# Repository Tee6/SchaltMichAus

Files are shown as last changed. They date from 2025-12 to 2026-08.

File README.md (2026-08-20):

# SchaltMichAus

**SchaltMichAus** is a smart add-on for my audio setup (Yamaha RX-V1065), now built around **Home Assistant** as the primary control layer via **MQTT**.
It monitors the receiver's activity, exposes trigger/music state as Home Assistant entities, and automatically shuts down the receiver via IR when no audio is playing.

**Goal:**
Reduce energy consumption, avoid unnecessary idle time, and extend the lifetime of the receiver – fully integrated into my smart home, without changing how the setup is normally used.

## Motivation

I inherited a Yamaha RX-V1065 from my grandpa.
Whenever someone in the flat listened to music in the evening, we often forgot to turn the amplifier off. Managing the peripherals manually or switching the TV audio output every time was inconvenient. I wanted a solution that:

- does not change how the receiver is used,
- requires no firmware or hardware modifications to the receiver itself,
- integrates cleanly into Home Assistant,
- and keeps the device as my grandpa left it.

## Features

- **Home Assistant integration (MQTT)**
  - ESP32 publishes trigger state, music-active state, and switch state via MQTT with HA Discovery – all entities show up automatically in Home Assistant, no manual YAML config needed.
  - A dedicated switch entity lets me manually trigger a shutdown from HA, alongside automations (e.g. tied to presence, time of day, or other smart home logic).
  - This is now the main way the system is operated day-to-day.

- **Automatic idle detection**
  - Monitors the receiver's 12 V trigger output.
  - Analyzes the audio-out signal to detect real audio activity.
  - Marks the system as "inactive" after a configurable silence timeout.

- **Input Switching and Volume Control**
  - Can switch between Inputs for Record Player (Phono) and TV (Audio1).
  - With Home Assistant Automations, the Input gets automatically set for the TV and in the Future maybe even for the record player with an DIY sensor when i open the record player.
  - Volume can be controlled with Home Assistant.
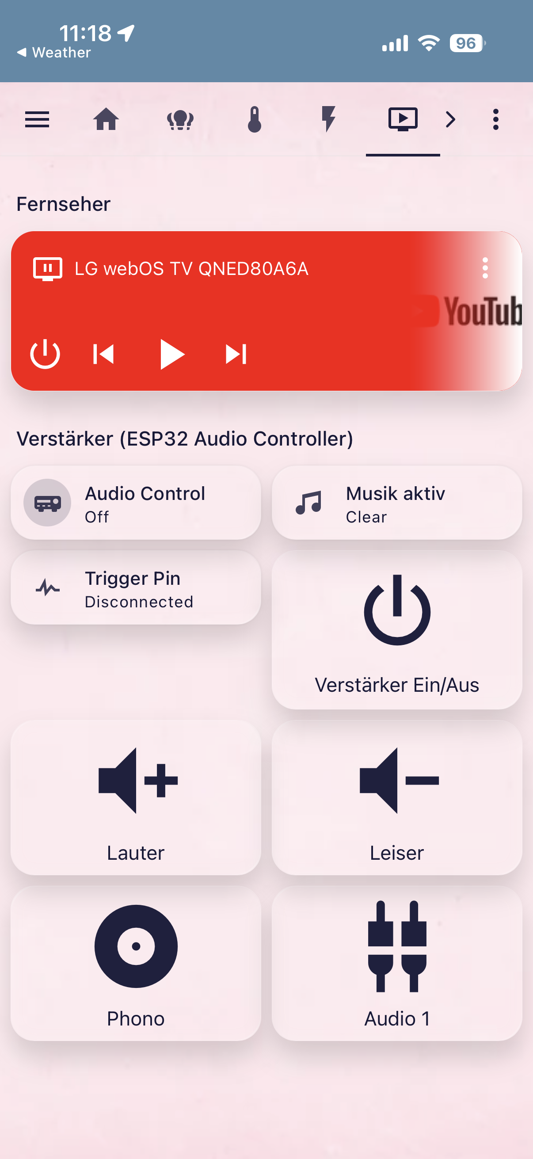
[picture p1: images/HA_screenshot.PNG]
Home Assistant Dashboard


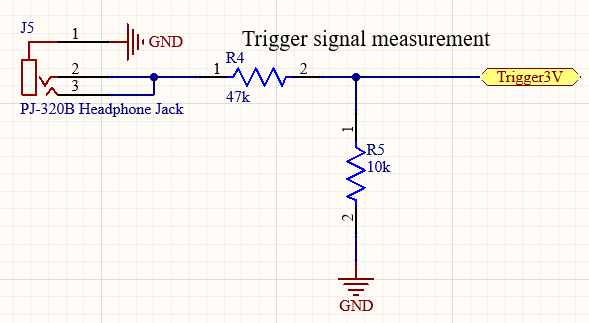
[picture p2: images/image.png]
Trigger Voltage measurement


Simple Voltage Divider

$U_m=12V*{10k\Omega \above{2pt} 10k\Omega+47k\Omega} \approx 2.1V$

- **Automatic receiver power-down – hardware fallback**
  - Independently of Home Assistant, the ESP32 itself tracks a **20-minute silence timeout**: if no music activity is detected for 20 minutes, it sends IR commands to the receiver for a clean shutdown – just like a remote.
  - This runs locally on the ESP32 regardless of whether HA, MQTT, or WiFi are available, so the amp still gets shut off even if the smart home stack is down.

- **Load switch (present on PCB, currently unused)**
  - The custom PCB still includes a load switch, originally used to power down the ARC extractor and other peripherals.
  - Since the ARC extractor is no longer part of the setup (audio now goes via Bluetooth), the load switch is not currently used in this use case, but remains available on the board for future peripherals if needed.

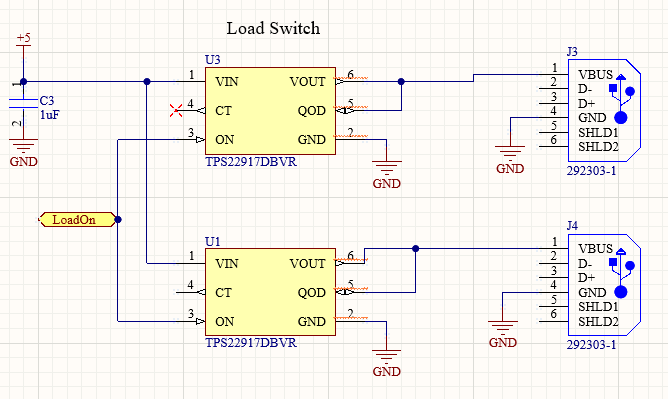
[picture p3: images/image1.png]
LoadSwitches


Load Switches parallel so the current is less of a problem. We only need Power so D- and D+ are left floating.

- **Non-intrusive integration**
  - Installed between the receiver's audio/trigger outputs and the peripherals.
  - Requires no modification of the receiver.
  - Works completely in the background.

- **Smart audio detection**
  - Uses a DC-biased input and statistical deviation ("loudness over time") to detect meaningful audio.
  - Avoids false shutdowns during quiet passages or short pauses.

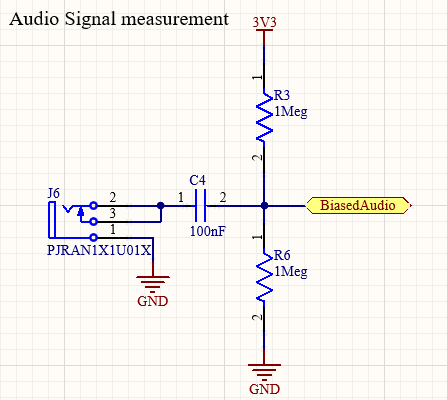
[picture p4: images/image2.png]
audio-measurement


Audio Signal is biased to $3.3V / 2 =1.65V$ because IO Pin cant handle negative Voltage

- **Bluetooth audio path (replaces ARC extractor)**
  - The previous ARC extractor is no longer used.
  - The TV now sends its audio directly to the receiver over **Bluetooth**, simplifying the signal chain and removing the extra ARC hardware step entirely.

## Typical Use Case

1. TV audio is streamed to the receiver via Bluetooth (or another source is played, e.g. turntable via phono).
2. SchaltMichAus detects the active state via the trigger signal and begins monitoring audio.
3. Trigger and music state are visible live in Home Assistant, and I can control shutdown manually or via HA automations.
4. During playback, the receiver stays on; ESP32 and Bluetooth module run continuously in the background regardless.
5. After playback stops:
   - If controlled via Home Assistant, automations can react to the published state as configured.
   - Independently, after the configured silence interval (20 min) passes with no music detected, the receiver is turned off via IR – this happens regardless of HA availability.

**Result:**
No more receiver running for hours after someone forgot to turn it off, now with full Home Assistant visibility and control on top of the standalone hardware safety net.

## Hardware Overview

- **Controller:** ESP32 (AZ-Delivery version)
- **Inputs:**
  - 5 V via USB-C
  - 12 V trigger input
  - Audio-out signal (approx. ±1 V)
- **Outputs:**
  - IR LED for power commands to the receiver
  - Load switch (on PCB, currently unused – previously powered ARC extractor)
- **Connectivity:**
  - MQTT to Home Assistant, with HA Discovery for switch, trigger, and music-active entities
  - Bluetooth receiver module (TV → receiver audio path), running continuously

## Status

- Home Assistant / MQTT integration: **working**
- IR on/off control: **working**
- Trigger signal monitoring: **working**
- Audio-based idle detection: **working**
- 20-minute hardware silence shutdown (independent of HA): **working**
- Bluetooth audio path (TV → receiver): **working**
- Custom PCB with ESP32, audio and trigger inputs, load switch: **working** (load switch currently unused in this setup)

## Initial Problems

- The first ESP32 unit was unreliable, causing inconsistent behaviour → resolved by replacing it.
- Audio detection pin was not ADC-capable → fixed by soldering a jumper wire to a valid ADC pin.

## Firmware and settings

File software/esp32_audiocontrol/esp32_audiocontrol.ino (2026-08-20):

#include <Arduino.h>
#define MQTT_MAX_PACKET_SIZE 1024

#include <WiFi.h>
#include <IRremoteESP8266.h>
#include <IRsend.h>
#include <string.h>
#include <PubSubClient.h>

// ---------------- WLAN ----------------
const char* ssid = "";
const char* password = "";

// ---------------- MQTT ----------------
const char* mqttBroker   = "192.168.178.113"; // ggf. ändern
const int   mqttPort     = 1883;
const char* mqttUser     = "esp32";
const char* mqttPassword = "esp32";

#define MQTT_PREFIX        "homeassistant"
#define DEVICE_ID          "esp32_audiocontrol"

#define TOPIC_SWITCH_CMD    DEVICE_ID "/switch/control/set"
#define TOPIC_SWITCH_STATE  DEVICE_ID "/switch/control/state"
#define TOPIC_TRIGGER_STATE DEVICE_ID "/binary_sensor/trigger/state"
#define TOPIC_MUSIC_STATE   DEVICE_ID "/binary_sensor/music/state"
#define TOPIC_IR_CMD        DEVICE_ID "/button/ir_send/set"
#define TOPIC_IR_EVENT      DEVICE_ID "/sensor/ir_event/state"

#define TOPIC_DISC_SWITCH   MQTT_PREFIX "/switch/"        DEVICE_ID "_control/config"
#define TOPIC_DISC_TRIGGER  MQTT_PREFIX "/binary_sensor/" DEVICE_ID "_trigger/config"
#define TOPIC_DISC_MUSIC    MQTT_PREFIX "/binary_sensor/" DEVICE_ID "_music/config"
#define TOPIC_DISC_IR       MQTT_PREFIX "/button/"        DEVICE_ID "_ir_send/config"
#define TOPIC_DISC_IR_EVENT MQTT_PREFIX "/sensor/"        DEVICE_ID "_ir_event/config"

// NEU: Discovery-Topics für die vier zusätzlichen Buttons
#define TOPIC_DISC_VOL_UP   MQTT_PREFIX "/button/" DEVICE_ID "_vol_up/config"
#define TOPIC_DISC_VOL_DOWN MQTT_PREFIX "/button/" DEVICE_ID "_vol_down/config"
#define TOPIC_DISC_PHONO    MQTT_PREFIX "/button/" DEVICE_ID "_in_phono/config"
#define TOPIC_DISC_AUDIO1   MQTT_PREFIX "/button/" DEVICE_ID "_in_audio1/config"

// ---------------- Pins ----------------
#define PIN_TRIGGER 32
#define PIN_IR      18
#define AUX_PIN     34

// ---------------- Audio ----------------
#define SAMPLE_COUNT      1000
const float THRESH_ON   =  8.0f;
const float THRESH_OFF  = 12.0f;
#define MUSIC_ON_CONFIRM  3
#define MUSIC_OFF_CONFIRM 6

float g_silenceMinutes = 20.0f;

// Mindest-Wartezeit nach Trigger-HIGH bevor Silence-Timeout greifen darf
const unsigned long TRIGGER_GRACE_MS = 30000UL;  // 30 Sekunden

// Schutzfenster nach MQTT-Connect: retained Messages in diesem Fenster ignorieren
const unsigned long MQTT_RETAINED_IGNORE_MS = 2000UL;

// Debounce für manuellen POWER-Press: verhindert Doppel-Toggle egal welche Ursache
const unsigned long MANUAL_IR_DEBOUNCE_MS = 3000UL;

// Kurzer Debounce für Vol/Input: nur gegen MQTT-Doppelzustellung,
// darf schnelles wiederholtes Drücken (Lautstärke!) NICHT blockieren
const unsigned long SHORT_IR_DEBOUNCE_MS = 250UL;

// ---------------- Timing ----------------
const unsigned long MUSIC_CHECK_MS        = 3000UL;
const unsigned long STATE_PRINT_MS        = 5000UL;
const unsigned long IR_INTERVAL_MS        = 2000UL;
const unsigned long MQTT_RECONNECT_MS     = 10000UL;
const unsigned long WIFI_RECONNECT_MS     = 15000UL;
const unsigned long DISCOVERY_INTERVAL_MS = 300000UL;

// ---------------- Yamaha IR Codes (aus LIRC RAV294 / RX-V1065) ----------------
#define YAMAHA_KEY_POWER   0x7E8154AB
#define YAMAHA_VOL_UP      0x5EA158A7   // KEY_VOLUMEUP
#define YAMAHA_VOL_DOWN    0x5EA1D827   // KEY_VOLUMEDOWN
#define YAMAHA_IN_PHONO    0x5EA128D7   // INPUT_PHONO
#define YAMAHA_IN_AUDIO1   0x5EA1A658   // INPUT_AUDIO1

// ---------------- Globals ----------------
WiFiClient   wifiClient;
PubSubClient mqtt(wifiClient);
IRsend       irsend(PIN_IR);

bool g_wifiReady       = false;
bool g_haControlOn     = false;
bool g_haControlOff    = false;

bool g_lastTriggerPub  = false;
bool g_lastMusicPub    = false;
bool g_musicActive     = false;
bool g_shutdownMode    = false;
bool g_triggerState    = false;
bool g_musicEverActive = false;

int  g_musicOnCounter  = 0;
int  g_musicOffCounter = 0;

unsigned long g_lastIrSendTime    = 0;
unsigned long g_lastMqttAttempt   = 0;
unsigned long g_lastWifiAttempt   = 0;
unsigned long g_lastMusicTime     = 0;
unsigned long g_triggerHighTime   = 0;
unsigned long g_mqttConnectedAt   = 0;
unsigned long g_lastManualIrTime  = 0;
unsigned long g_lastShortIrTime   = 0;

// ================================================================
// Forward Declarations
// ================================================================
void sendIR(const char* reason);
void sendIRCode(uint32_t code, const char* reason);
void publishSwitchState(bool on);
void publishTriggerState(bool on);
void publishMusicState(bool on);
void publishIrEvent(const char* reason);
void publishDiscovery();
void ensureMQTT();
void ensureWiFi();

// ================================================================
// WiFi – non-blocking
// ================================================================
void ensureWiFi() {
  if (WiFi.status() == WL_CONNECTED) { g_wifiReady = true; return; }
  wl_status_t s = WiFi.status();
  if (s == WL_DISCONNECTED || s == WL_NO_SSID_AVAIL || s == WL_CONNECT_FAILED) {
    WiFi.mode(WIFI_STA);
    WiFi.begin(ssid, password);
  }
  g_wifiReady = (WiFi.status() == WL_CONNECTED);
}

// ================================================================
// MQTT Discovery
// ================================================================
void publishDiscovery() {
  mqtt.publish(TOPIC_DISC_SWITCH,
    "{"
      "\"name\":\"Audio Control\","
      "\"unique_id\":\"" DEVICE_ID "_control\","
      "\"command_topic\":\"" TOPIC_SWITCH_CMD "\","
      "\"state_topic\":\"" TOPIC_SWITCH_STATE "\","
      "\"payload_on\":\"ON\","
      "\"payload_off\":\"OFF\","
      "\"retain\":true,"
      "\"device\":{"
        "\"identifiers\":[\"" DEVICE_ID "\"],"
        "\"name\":\"ESP32 Audio Controller\","
        "\"model\":\"ESP32\","
        "\"manufacturer\":\"DIY\""
      "}"
    "}", true);

  mqtt.publish(TOPIC_DISC_TRIGGER,
    "{"
      "\"name\":\"Trigger Pin\","
      "\"unique_id\":\"" DEVICE_ID "_trigger\","
      "\"state_topic\":\"" TOPIC_TRIGGER_STATE "\","
      "\"payload_on\":\"ON\","
      "\"payload_off\":\"OFF\","
      "\"device_class\":\"connectivity\","
      "\"retain\":true,"
      "\"device\":{\"identifiers\":[\"" DEVICE_ID "\"],\"name\":\"ESP32 Audio Controller\"}"
    "}", true);

  mqtt.publish(TOPIC_DISC_MUSIC,
    "{"
      "\"name\":\"Musik aktiv\","
      "\"unique_id\":\"" DEVICE_ID "_music\","
      "\"state_topic\":\"" TOPIC_MUSIC_STATE "\","
      "\"payload_on\":\"ON\","
      "\"payload_off\":\"OFF\","
      "\"device_class\":\"sound\","
      "\"retain\":true,"
      "\"device\":{\"identifiers\":[\"" DEVICE_ID "\"],\"name\":\"ESP32 Audio Controller\"}"
    "}", true);

  mqtt.publish(TOPIC_DISC_IR,
    "{"
      "\"name\":\"IR Senden\","
      "\"unique_id\":\"" DEVICE_ID "_ir_send\","
      "\"command_topic\":\"" TOPIC_IR_CMD "\","
      "\"payload_press\":\"PRESS\","
      "\"device\":{"
        "\"identifiers\":[\"" DEVICE_ID "\"],"
        "\"name\":\"ESP32 Audio Controller\","
        "\"model\":\"ESP32\","
        "\"manufacturer\":\"DIY\""
      "}"
    "}", true);

  // NEU: Vier weitere Buttons. Gleiches command_topic, unterschiedliche payload_press.
  // Vorteil: nur eine Subscription, Retained-Handling & Startup-Schutz gelten automatisch.
  mqtt.publish(TOPIC_DISC_VOL_UP,
    "{"
      "\"name\":\"Lautstärke +\","
      "\"unique_id\":\"" DEVICE_ID "_vol_up\","
      "\"command_topic\":\"" TOPIC_IR_CMD "\","
      "\"payload_press\":\"VOL_UP\","
      "\"icon\":\"mdi:volume-plus\","
      "\"device\":{\"identifiers\":[\"" DEVICE_ID "\"],\"name\":\"ESP32 Audio Controller\"}"
    "}", true);

  mqtt.publish(TOPIC_DISC_VOL_DOWN,
    "{"
      "\"name\":\"Lautstärke -\","
      "\"unique_id\":\"" DEVICE_ID "_vol_down\","
      "\"command_topic\":\"" TOPIC_IR_CMD "\","
      "\"payload_press\":\"VOL_DOWN\","
      "\"icon\":\"mdi:volume-minus\","
      "\"device\":{\"identifiers\":[\"" DEVICE_ID "\"],\"name\":\"ESP32 Audio Controller\"}"
    "}", true);

  mqtt.publish(TOPIC_DISC_PHONO,
    "{"
      "\"name\":\"Input Phono\","
      "\"unique_id\":\"" DEVICE_ID "_in_phono\","
      "\"command_topic\":\"" TOPIC_IR_CMD "\","
      "\"payload_press\":\"PHONO\","
      "\"icon\":\"mdi:album\","
      "\"device\":{\"identifiers\":[\"" DEVICE_ID "\"],\"name\":\"ESP32 Audio Controller\"}"
    "}", true);

  mqtt.publish(TOPIC_DISC_AUDIO1,
    "{"
      "\"name\":\"Input Audio1\","
      "\"unique_id\":\"" DEVICE_ID "_in_audio1\","
      "\"command_topic\":\"" TOPIC_IR_CMD "\","
      "\"payload_press\":\"AUDIO1\","
      "\"icon\":\"mdi:audio-input-rca\","
      "\"device\":{\"identifiers\":[\"" DEVICE_ID "\"],\"name\":\"ESP32 Audio Controller\"}"
    "}", true);

  mqtt.publish(TOPIC_DISC_IR_EVENT,
    "{"
      "\"name\":\"IR Letzter Grund\","
      "\"unique_id\":\"" DEVICE_ID "_ir_event\","
      "\"state_topic\":\"" TOPIC_IR_EVENT "\","
      "\"retain\":true,"
      "\"icon\":\"mdi:remote\","
      "\"device\":{"
        "\"identifiers\":[\"" DEVICE_ID "\"],"
        "\"name\":\"ESP32 Audio Controller\","
        "\"model\":\"ESP32\","
        "\"manufacturer\":\"DIY\""
      "}"
    "}", true);
}

// ================================================================
// MQTT Callback
// ================================================================
void mqttCallback(char* topic, byte* payload, unsigned int length) {
  char msg[16] = {0};
  unsigned int copyLen = (length < 15) ? length : 15;
  memcpy(msg, payload, copyLen);
  Serial.printf("MQTT [%s]: %s\n", topic, msg);

  if (strcmp(topic, TOPIC_SWITCH_CMD) == 0) {
    if (strcmp(msg, "ON") == 0) {
      g_haControlOn  = true;
      g_haControlOff = false;
    } else if (strcmp(msg, "OFF") == 0) {
      if (millis() - g_mqttConnectedAt < MQTT_RETAINED_IGNORE_MS) {
        Serial.println("MQTT OFF ignoriert: retained (Startup)");
        publishSwitchState(true);
      } else {
        g_haControlOff = true;
        g_haControlOn  = false;
      }
    }
  }

  if (strcmp(topic, TOPIC_IR_CMD) == 0) {

    // FIX: nur clearen wenn die Nachricht tatsächlich Inhalt hatte.
    // Vorher wurde hier IMMER (auch bei leerer Nachricht) erneut auf
    // dasselbe Topic publiziert, auf das der ESP32 selbst subscribed ist.
    // Das erzeugte eine Self-Feedback-Loop: publish("") -> eigener Empfang
    // -> erneutes publish("") -> ... im Millisekundentakt.
    if (length > 0) {
      mqtt.publish(TOPIC_IR_CMD, "", true);  // Retained Press löschen
    } else {
      return;  // leere Clear-Nachricht: nichts weiter tun
    }

    unsigned long now = millis();

    // Schutzfenster: Press kurz nach Connect = retained, ignorieren.
    // Gilt für ALLE Button-Payloads (POWER, VOL, INPUT).
    if (millis() - g_mqttConnectedAt < MQTT_RETAINED_IGNORE_MS) {
      Serial.println("MQTT Press ignoriert: retained (Startup)");
      return;
    }

    // ---- POWER (langer Debounce, Doppel-Toggle wäre fatal) ----
    if (strcmp(msg, "PRESS") == 0) {
      if (now - g_lastManualIrTime < MANUAL_IR_DEBOUNCE_MS) {
        Serial.println("MQTT IR PRESS ignoriert: Debounce (zu kurz nach letztem Press)");
        return;
      }
      g_lastManualIrTime = now;
      Serial.println("HA Button: IR manuell (POWER)");
      sendIR("manual_ha");
      return;
    }

    // ---- Vol/Input (kurzer Debounce: schnelles Drücken erlaubt) ----
    if (now - g_lastShortIrTime < SHORT_IR_DEBOUNCE_MS) {
      Serial.println("MQTT Press ignoriert: Kurz-Debounce");
      return;
    }

    if (strcmp(msg, "VOL_UP") == 0) {
      g_lastShortIrTime = now;
      sendIRCode(YAMAHA_VOL_UP, "vol_up");
    } else if (strcmp(msg, "VOL_DOWN") == 0) {
      g_lastShortIrTime = now;
      sendIRCode(YAMAHA_VOL_DOWN, "vol_down");
    } else if (strcmp(msg, "PHONO") == 0) {
      g_lastShortIrTime = now;
      sendIRCode(YAMAHA_IN_PHONO, "input_phono");
    } else if (strcmp(msg, "AUDIO1") == 0) {
      g_lastShortIrTime = now;
      sendIRCode(YAMAHA_IN_AUDIO1, "input_audio1");
    }
  }
}

// ================================================================
// MQTT Reconnect
// ================================================================
void ensureMQTT() {
  if (mqtt.connected() || !g_wifiReady) return;
  Serial.print("MQTT verbinden...");
  mqtt.setKeepAlive(60);
  bool ok = (strlen(mqttUser) > 0)
    ? mqtt.connect(DEVICE_ID, mqttUser, mqttPassword)
    : mqtt.connect(DEVICE_ID);
  if (ok) {
    Serial.println(" OK");
    g_mqttConnectedAt = millis();  // bei JEDEM Connect (auch Reconnect) setzen
    mqtt.subscribe(TOPIC_SWITCH_CMD);
    mqtt.subscribe(TOPIC_IR_CMD);
    delay(500);
    publishDiscovery();
  } else {
    Serial.printf(" fehlgeschlagen rc=%d\n", mqtt.state());
  }
}

// ================================================================
// Publish Helpers
// ================================================================
void publishSwitchState(bool on) {
  if (mqtt.connected()) mqtt.publish(TOPIC_SWITCH_STATE, on ? "ON" : "OFF", true);
}
void publishTriggerState(bool on) {
  if (mqtt.connected()) mqtt.publish(TOPIC_TRIGGER_STATE, on ? "ON" : "OFF", true);
}
void publishMusicState(bool on) {
  if (mqtt.connected()) mqtt.publish(TOPIC_MUSIC_STATE, on ? "ON" : "OFF", true);
}

void publishIrEvent(const char* reason) {
  if (!mqtt.connected()) return;
  char payload[128];
  snprintf(payload, sizeof(payload),
    "{\"reason\":\"%s\",\"ts\":%lu}", reason, millis());
  mqtt.publish(TOPIC_IR_EVENT, payload, true);
}

// ================================================================
// IR – generisch mit Code + Grund
// ================================================================
void sendIRCode(uint32_t code, const char* reason) {
  Serial.printf("IR: 0x%08X | Grund: %s\n", code, reason);
  irsend.sendNEC(code, 32);
  publishIrEvent(reason);
}

// POWER bleibt als eigene Funktion (wird auch vom Silence-Timeout genutzt)
void sendIR(const char* reason) {
  sendIRCode(YAMAHA_KEY_POWER, reason);
}

// ================================================================
// Audio Messung
// ================================================================
float measureStddev() {
  long sum = 0;
  int samples[SAMPLE_COUNT];
  for (int i = 0; i < SAMPLE_COUNT; i++) { samples[i] = analogRead(AUX_PIN); sum += samples[i]; }
  float mean = (float)sum / SAMPLE_COUNT;
  float variance = 0.0f;
  for (int i = 0; i < SAMPLE_COUNT; i++) { float d = samples[i] - mean; variance += d * d; }
  return sqrtf(variance / SAMPLE_COUNT);
}

// ================================================================
// SETUP
// ================================================================
void setup() {
  Serial.begin(115200);
  delay(200);
  pinMode(PIN_TRIGGER, INPUT);
  pinMode(PIN_IR, OUTPUT);
  analogReadResolution(12);
  irsend.begin();

  WiFi.mode(WIFI_STA);
  WiFi.begin(ssid, password);
  unsigned long wifiStart = millis();
  while (WiFi.status() != WL_CONNECTED && millis() - wifiStart < 8000) delay(100);
  g_wifiReady = (WiFi.status() == WL_CONNECTED);

  mqtt.setServer(mqttBroker, mqttPort);
  mqtt.setKeepAlive(60);
  mqtt.setBufferSize(1024);
  mqtt.setCallback(mqttCallback);
  ensureMQTT();

  g_triggerState    = (digitalRead(PIN_TRIGGER) == HIGH);
  g_lastMusicTime   = millis();
  g_triggerHighTime = millis();

  publishTriggerState(g_triggerState);
  publishSwitchState(g_triggerState);

  Serial.printf("Gestartet. Trigger=%s Silence=%.2f min\n",
    g_triggerState ? "HIGH" : "LOW", g_silenceMinutes);
}

// ================================================================
// LOOP
// ================================================================
void loop() {
  unsigned long now = millis();

  if (!g_wifiReady && now - g_lastWifiAttempt > WIFI_RECONNECT_MS) {
    g_lastWifiAttempt = now; ensureWiFi();
  }
  if (!mqtt.connected() && now - g_lastMqttAttempt > MQTT_RECONNECT_MS) {
    g_lastMqttAttempt = now; ensureWiFi(); ensureMQTT();
  }
  mqtt.loop();

  static unsigned long lastDiscovery = 0;
  if (mqtt.connected() && now - lastDiscovery >= DISCOVERY_INTERVAL_MS) {
    lastDiscovery = now; publishDiscovery();
  }

  // ---- HA Befehle ----
  if (g_haControlOff) { g_haControlOff = false; publishSwitchState(false); }
  if (g_haControlOn)  { g_haControlOn  = false; publishSwitchState(true);  }

  // ---- Trigger Pin ----
  bool triggerNow = (digitalRead(PIN_TRIGGER) == HIGH);
  if (triggerNow != g_lastTriggerPub) {
    g_lastTriggerPub = triggerNow;
    publishTriggerState(triggerNow);
    Serial.printf("Trigger: %s\n", triggerNow ? "HIGH" : "LOW");

    if (triggerNow) {
      g_shutdownMode    = false;
      g_musicActive     = false;
      g_musicEverActive = false;
      g_musicOnCounter  = 0;
      g_musicOffCounter = 0;
      g_lastMusicTime   = now;
      g_triggerHighTime = now;
      g_lastMusicPub    = false;
      publishSwitchState(true);
      publishMusicState(false);
    } else {
      g_musicActive     = false;
      g_musicEverActive = false;
      g_shutdownMode    = false;
      if (g_lastMusicPub) { g_lastMusicPub = false; publishMusicState(false); }
      publishSwitchState(false);
    }
  }
  g_triggerState = triggerNow;

  // ---- Audio Monitoring ----
  static unsigned long lastMusicCheck = 0;
  if (g_triggerState && !g_shutdownMode && now - lastMusicCheck >= MUSIC_CHECK_MS) {
    lastMusicCheck = now;
    float stddev = measureStddev();
    Serial.printf("Stddev: %.2f | OnCnt=%d OffCnt=%d\n",
      stddev, g_musicOnCounter, g_musicOffCounter);

    if (!g_musicActive) {
      if (stddev > THRESH_ON)          g_musicOnCounter++;
      else if (g_musicOnCounter > 0)   g_musicOnCounter--;
      if (g_musicOnCounter >= MUSIC_ON_CONFIRM) {
        g_musicActive     = true;
        g_musicEverActive = true;
        g_musicOffCounter = 0;
        Serial.println("Musik: AN");
      }
    } else {
      if (stddev < THRESH_OFF)          g_musicOffCounter++;
      else if (g_musicOffCounter > 0)   g_musicOffCounter--;
      if (g_musicOffCounter >= MUSIC_OFF_CONFIRM) {
        g_musicActive    = false;
        g_musicOnCounter = 0;
        Serial.println("Musik: AUS");
      }
    }

    if (g_musicActive) g_lastMusicTime = now;

    if (g_musicActive != g_lastMusicPub) {
      g_lastMusicPub = g_musicActive;
      publishMusicState(g_musicActive);
    }

    unsigned long silenceMs = (unsigned long)(g_silenceMinutes * 60.0f * 1000.0f);
    bool graceOver = (now - g_triggerHighTime >= TRIGGER_GRACE_MS);

    if ((g_musicEverActive || graceOver) && now - g_lastMusicTime >= silenceMs) {
      Serial.println("Stille-Timeout -> Shutdown");
      g_shutdownMode   = true;
      g_lastIrSendTime = 0;
      publishSwitchState(false);
    }
  }

  // ---- IR Shutdown Sequenz ----
  if (g_shutdownMode) {
    if (g_lastIrSendTime == 0 || now - g_lastIrSendTime >= IR_INTERVAL_MS) {
      g_lastIrSendTime = now;
      sendIR("silence_timeout");
    }
  }

  // ---- Serial Status ----
  static unsigned long lastPrint = 0;
  if (now - lastPrint >= STATE_PRINT_MS) {
    lastPrint = now;
    float silenceSec = g_triggerState ? (now - g_lastMusicTime) / 1000.0f : 0.0f;
    Serial.printf(
      "[%s] Trigger=%s Music=%s EverActive=%s MQTT=%s | Stille=%.1fs / Timeout=%.0fs\n",
      g_shutdownMode ? "SHUTDOWN" : (g_triggerState ? "AKTIV" : "IDLE"),
      g_triggerState ? "HIGH" : "LOW",
      g_musicActive  ? "JA"  : "NEIN",
      g_musicEverActive ? "JA" : "NEIN",
      mqtt.connected() ? "OK" : "ERR",
      silenceSec,
      g_silenceMinutes * 60.0f
    );
  }

  delay(5);
}

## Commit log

2025-12-06 Initial commit: added schematics and Board Files (Altium)
    [SchaltmichAus.PcbDoc, SchaltmichAus.SchDoc, schaltmichaus.PrjPcb]
2025-12-06 Enhance README with images and voltage details
    Added images and voltage calculations to README.
2026-08-20 added input switching and new HA icons
2026-10-30 Added every remote control feature available
    Added new IR button handling and extended discovery for buttons. Updated WiFi and MQTT configurations.
